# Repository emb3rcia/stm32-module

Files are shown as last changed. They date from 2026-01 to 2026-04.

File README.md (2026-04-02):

# stm32-module
Hello! This is my first MCU devboard, made for HackClub's Blueprint program. It features 66 goldpins, USB-C (USB-FS standard) port for data AND power, integrated 3.3V and 1.8V LDO and ESD protection on VBUS, DATA channels and CC channels! It uses 4 layer pcb (Front and Back are for power, IN1 and IN2 for GPIO connection). It uses STM32H7 64-LQFP Package MCU on it! I made it so I can have some devboard on hand as one-for-all. This is why theres so much power in this thing (384MHz!!!) and this many GPIO ports, and also why this has 1.8V LDO. You use it like any other devboard, **but note that it probably wont fit on breadboard, as it doesnt have the required distance present between connectors**

## Why i made it?

I thought it will be good learning project as well as giving me access to prototyping with mcu before commiting to making pcb. And i was right!

## What i learned:

Mainly how to deal with tight connection layout on PCB near MCU

# Images
Schematic v1 (old)

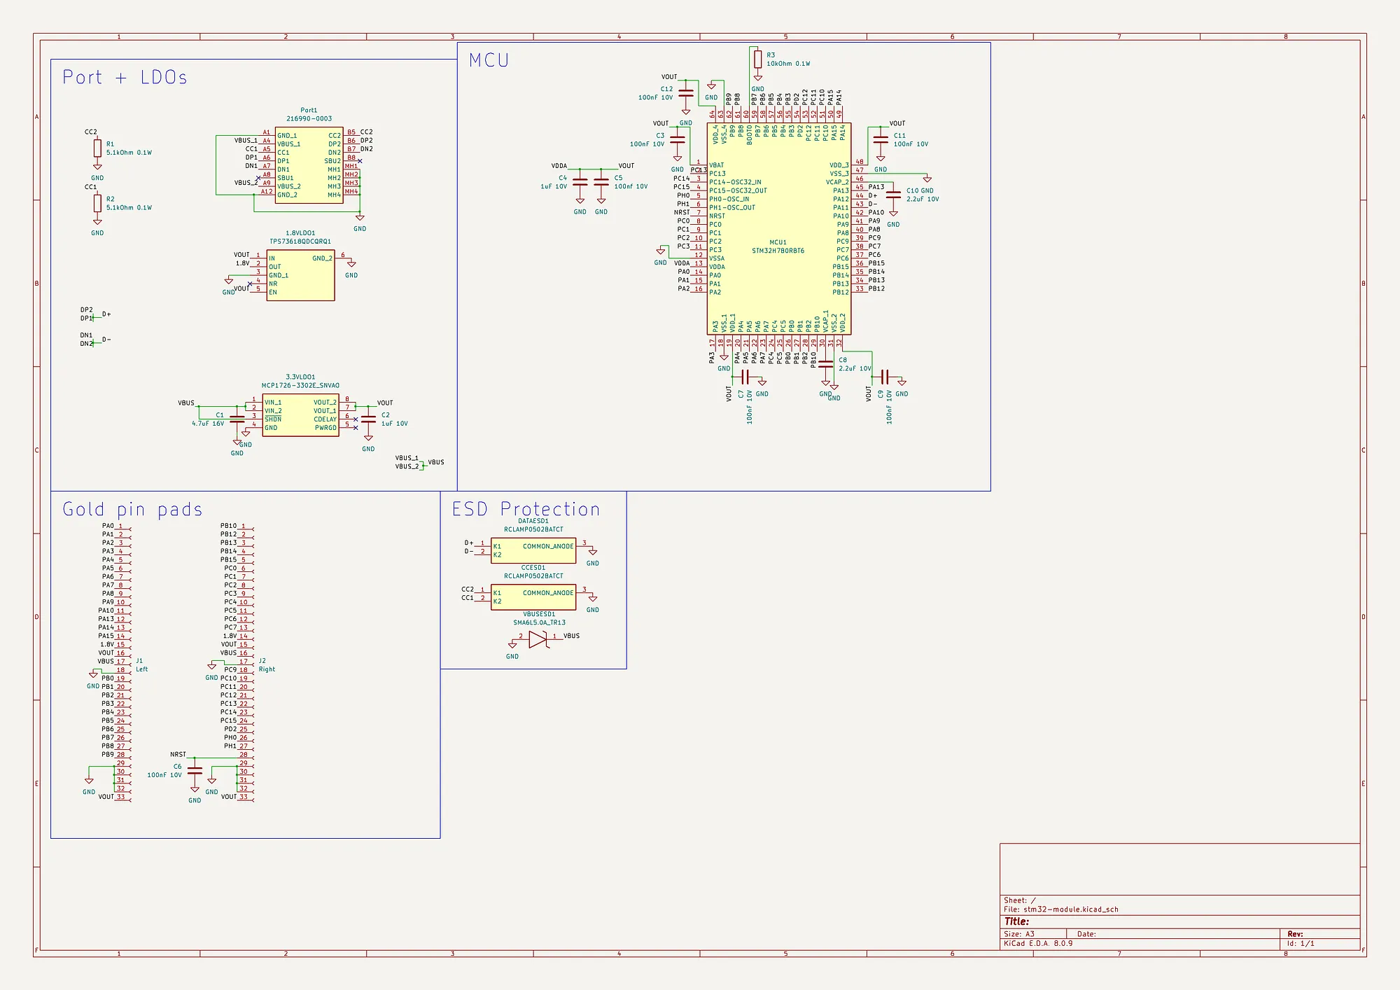
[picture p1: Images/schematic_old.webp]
Schematic v1 (old)


Schematic v1.5 (new, work in progress)

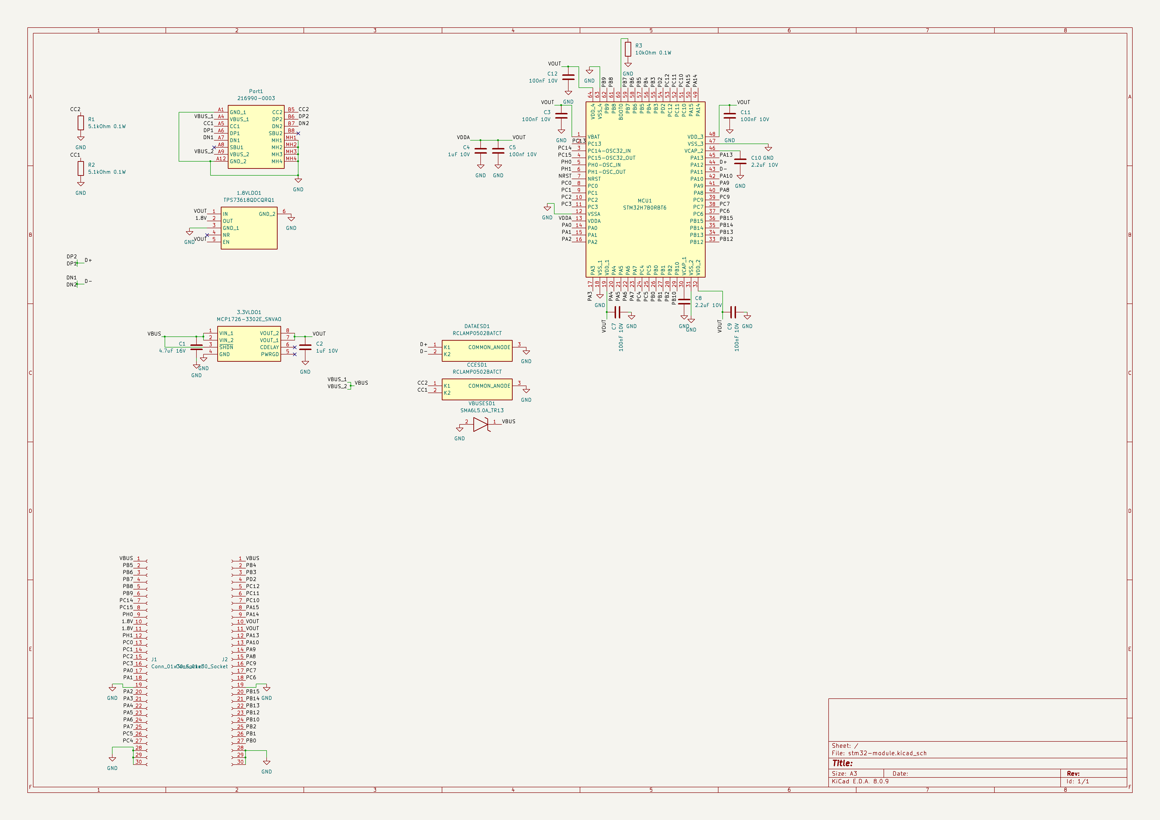
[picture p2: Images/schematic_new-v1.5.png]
Schematic v1.5 (new, work in progress)


Schematic v2 (new)

Schematic v2 (new)

PCB v1 (old, view via kicanvas so low quality screenshot, sorry)

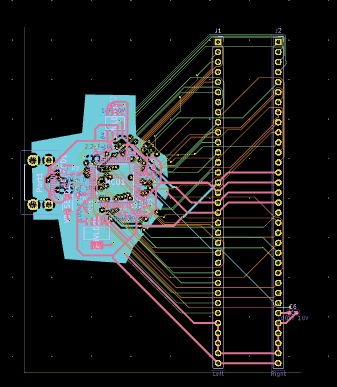
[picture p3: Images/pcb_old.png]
PCB v1 (old, view via kicanvas so low quality screenshot, sorry)


PCB v2 (new)

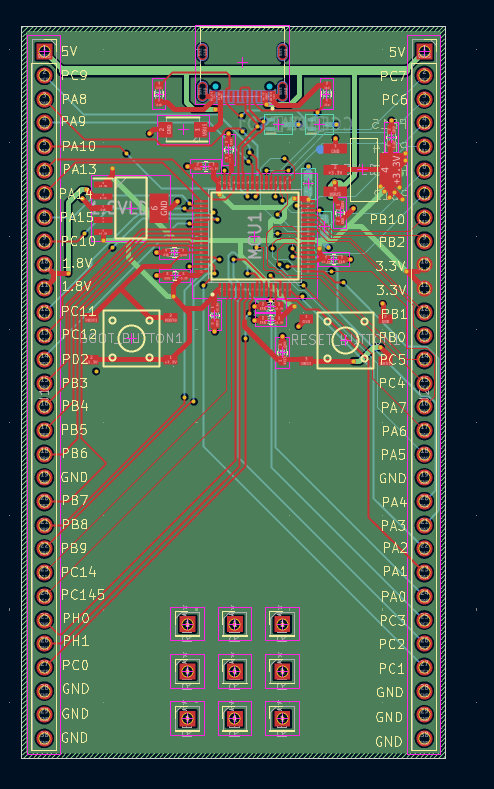
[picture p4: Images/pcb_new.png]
PCB v2 (new)


3D (new)

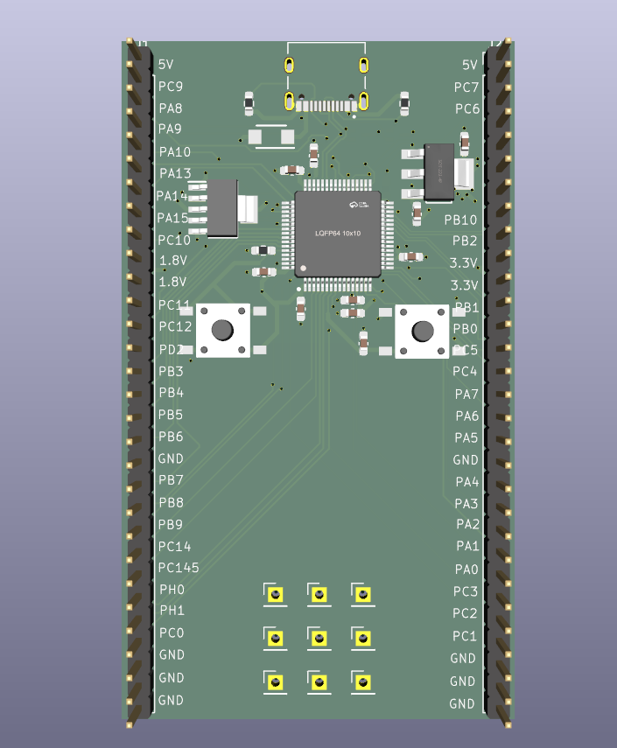
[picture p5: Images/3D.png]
3D (new)


# Q&A (no one said that but I want to include that lol)
> Traces look ugly

It is my second completed project overall. Also they weren't like high speed eg pcie so I just connected them as well as I can! I will try to make them nicer before production, but no promises. EDIT: Tried to make them nicer when rerouting everything, it worked like you can see.

# BOM
|Item |Description |Needed|Ordered|Why more/less? |Unit Price ($)|Total Price ($) |URL |
|---|---|---|---|---|---|---|---|
|ST STM32H7B0RBT6 |MCU |1 |1 |- |10.08$ |10.08$ |https://www.lcsc.com/product-detail/C730226.html |
|SEMTECH RCLAMP0502BATCT |CC and DATA lines esd |2 |5 |5 is minimal order amount |0.24$ |1.21$ |https://www.lcsc.com/product-detail/C117553.html |
|Littelfuse SMA6L5.0A |VBUS line esd |1 |1 |- |0.79$ |0.79$ |https://www.lcsc.com/product-detail/C1974860.html|
|BL BL8072CLTR33 |3.3V LDO |1 |5 |5 is minimal order amount |0.19$ |0.97$ |https://www.lcsc.com/product-detail/C843780.html |
|TI TPS73618QDCQRQ1 |1.8V LDO |1 |1 |- |1.54$ |1.54$ |https://www.lcsc.com/product-detail/C2877946.html|
|muRata GRM188Z71C475KE21D |4.7uF capacitor |1 |10 |10 is minimal order amount |0.07$ |0.68$ |https://www.lcsc.com/product-detail/C389010.html |
|Samsung Electro-Mechanics CL10A105KA8NNNC|1uF capacitor |2 |0 |I have 48 left from other project|- |- |https://www.lcsc.com/product-detail/C5673.html |
|VISHAY VJ0603Y104JXQCW1BC |100nF decap capacitor |7 |10 |sold in increments of 5 |0.08$ |0.81$ |https://www.lcsc.com/product-detail/C3834925.html|
|Samsung Electro-Mechanics CL10A225KO8NNNC|2.2uF capacitor |2 |50 |50 is minimal order amount |0.0062$ |0.31$ |https://www.lcsc.com/product-detail/C23630.html  |
|UNI-ROYAL 0603WAF5101T5E |5.1kOhm 0.1w CC resistor |2 |100 |100 is minimal order amount |0.0012$ |0.12$ |https://www.lcsc.com/product-detail/C23186.html  |
|VISHAY CRCW060310K0DHEAP |10kOhm pull-up/down resistor|2 |5 |5 is minimal order amount |0.12$ |0.58$ |https://www.lcsc.com/product-detail/C3917708.html|
|SHOU HAN TS6643TP 250gf 009 |BOOT and NRST button |2 |50 |50 is minimal order amount |0.0167$ |0.84$ |https://www.lcsc.com/product-detail/C5342967.html|
|SHOU HAN TYPE-C 16PIN 2MD(073) |USB-C plug |1 |20 |20 is minimal order amount |0.06$ |1.26$ |https://www.lcsc.com/product-detail/C2765186.html|
|PCB |PCB |1 |5 |5 is minimal order amount |- |7$+1.5$ delivery|https://jlcpcb.com/ |

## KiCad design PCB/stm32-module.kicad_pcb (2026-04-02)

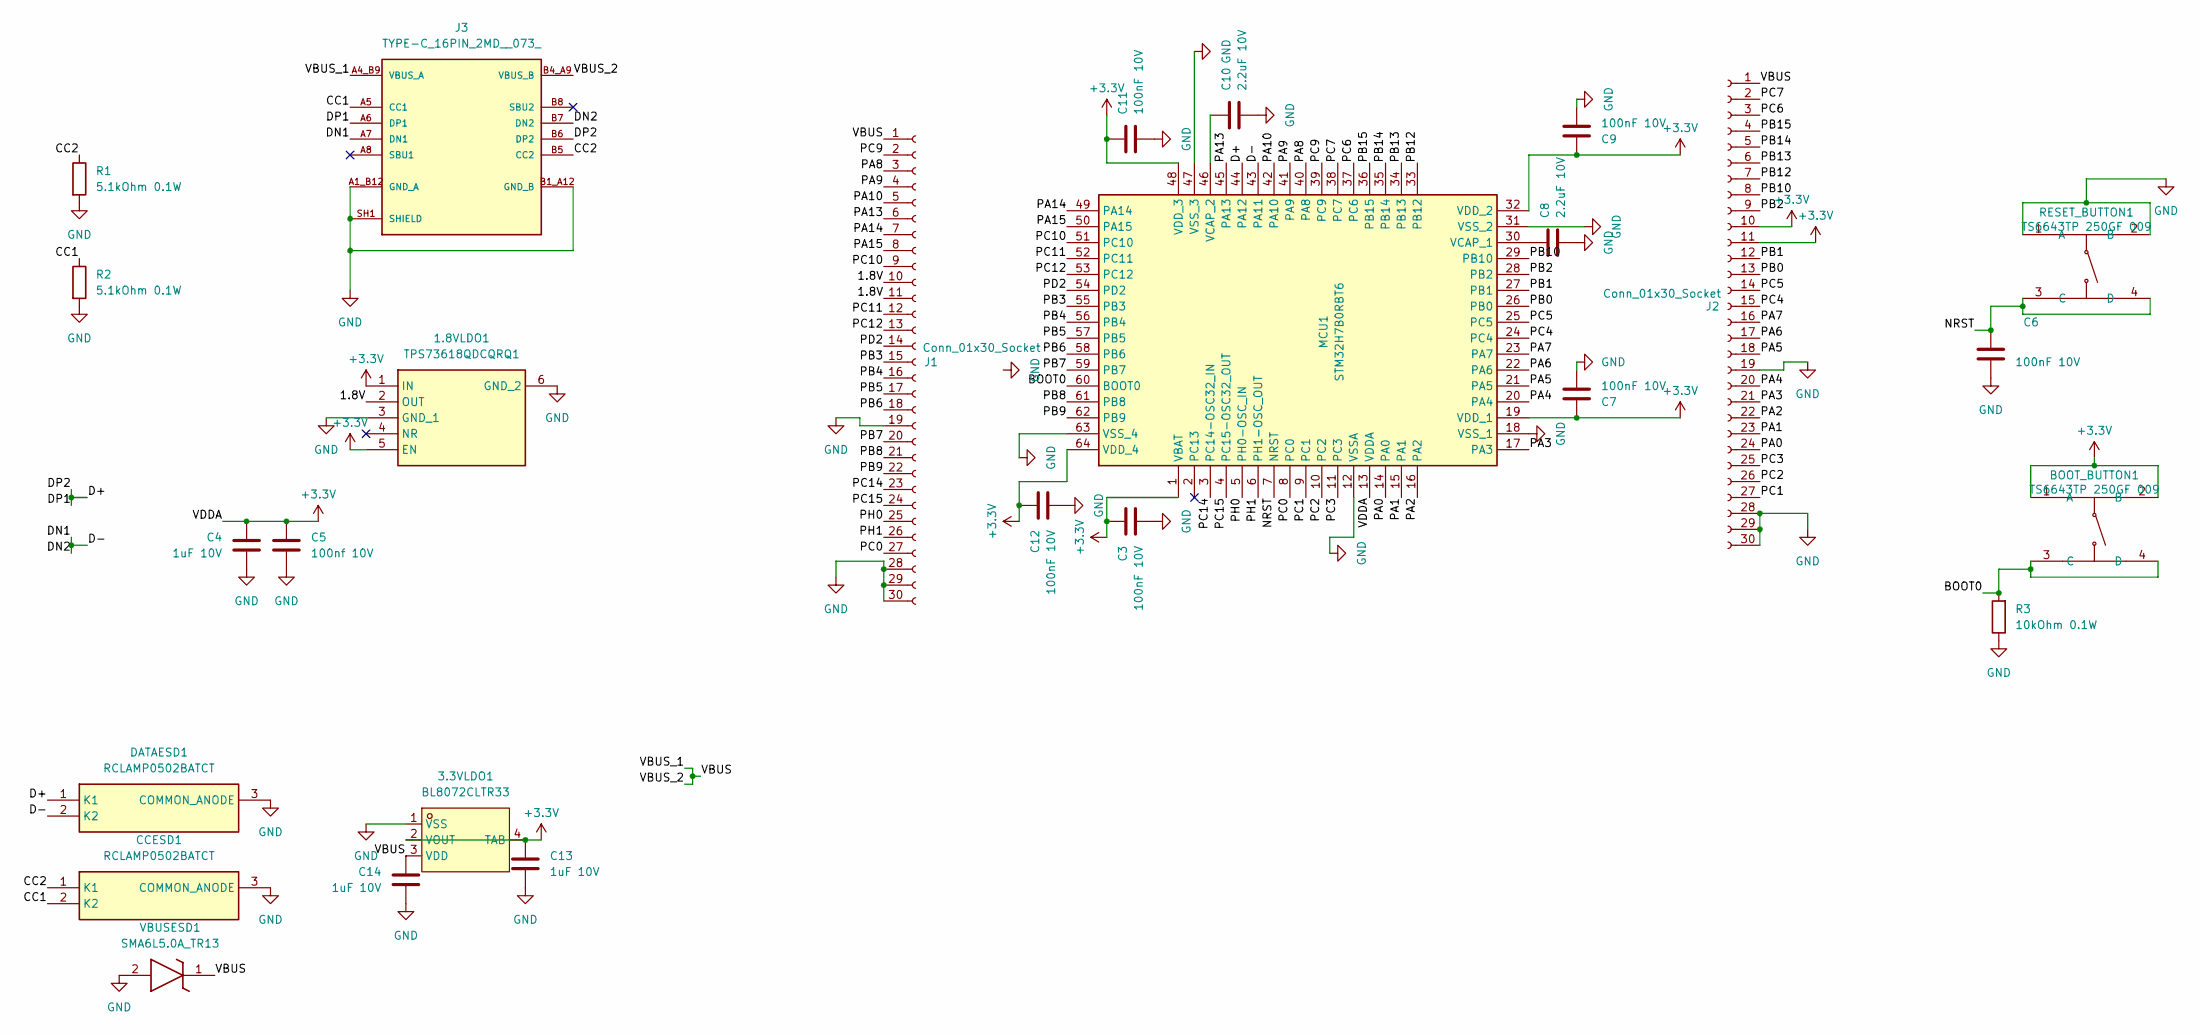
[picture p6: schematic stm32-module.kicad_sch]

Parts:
1.8VLDO1: TPS73618QDCQRQ1; SOT127P706X180-6N; Manufacturer_Part_Number TPS73618QDCQRQ1; Mouser Part Number 595-TPS73618QDCQRQ1
3.3VLDO1: BL8072CLTR33; SOT-223-3_L6.5-W3.4-P2.30-LS7.0-BR; LCSC Part C843780
BOOT_BUTTON1: TS6643TP 250GF 009; SW-SMD_4P-L6.2-W6.0-P4.50-LS9.0; LCSC Part C5342967
C3, C6, C7, C9, C11, C12: 100nF 10V; C_0603_1608Metric_Pad1.08x0.95mm_HandSolder
C4, C13, C14: 1uF 10V; C_0603_1608Metric_Pad1.08x0.95mm_HandSolder
C5: 100nf 10V; C_0603_1608Metric_Pad1.08x0.95mm_HandSolder
C8, C10: 2.2uF 10V; C_0603_1608Metric_Pad1.08x0.95mm_HandSolder
CCESD1: RCLAMP0502BATCT; SOT50P160X90-3N; Manufacturer_Part_Number RCLAMP0502BATCT; Mouser Part Number 947-RCLAMP0502BATCT
DATAESD1: RCLAMP0502BATCT; SOT50P160X90-3N; Manufacturer_Part_Number RCLAMP0502BATCT; Mouser Part Number 947-RCLAMP0502BATCT
J1, J2: Conn_01x30_Socket; PinSocket_1x30_P2.54mm_Vertical
J3: TYPE-C_16PIN_2MD__073_; SHOUHAN_TYPE-C_16PIN_2MD__073_; PARTREV A
MCU1: STM32H7B0RBT6; QFP50P1200X1200X160-64N; Manufacturer_Part_Number STM32H7B0RBT6; Mouser Part Number 511-STM32H7B0RBT6
R1, R2: 5.1kOhm 0.1W; R_0603_1608Metric_Pad0.98x0.95mm_HandSolder
R3: 10kOhm 0.1W; R_0603_1608Metric_Pad0.98x0.95mm_HandSolder
RESET_BUTTON1: TS6643TP 250GF 009; SW-SMD_4P-L6.2-W6.0-P4.50-LS9.0; LCSC Part C5342967
VBUSESD1: SMA6L5.0A_TR13; SODFL4626X140N; Manufacturer_Part_Number SMA6L5.0A/TR13

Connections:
+3.3V: 1.8VLDO1.1 (IN), 1.8VLDO1.5 (EN), 3.3VLDO1.2 (VOUT), 3.3VLDO1.4 (TAB), BOOT_BUTTON1.1 (A), BOOT_BUTTON1.2 (B), C3.1, C4.1, C5.1, C7.1, C9.1, C11.1, C12.1, C13.1, J2.10, J2.11, MCU1.1 (VBAT), MCU1.13 (VDDA), MCU1.19 (VDD_1), MCU1.32 (VDD_2), MCU1.48 (VDD_3), MCU1.64 (VDD_4)
/1.8V: 1.8VLDO1.2 (OUT), J1.10, J1.11
/BOOT0: BOOT_BUTTON1.3 (C), BOOT_BUTTON1.4 (D), MCU1.60 (BOOT0), R3.2
/CC1: CCESD1.2 (K2), J3.A5 (CC1), R2.1
/CC2: CCESD1.1 (K1), J3.B5 (CC2), R1.1
/D+: DATAESD1.1 (K1), J3.A6 (DP1), J3.B6 (DP2), MCU1.44 (PA12)
/D-: DATAESD1.2 (K2), J3.A7 (DN1), J3.B7 (DN2), MCU1.43 (PA11)
/NRST: C6.1, MCU1.7 (NRST), RESET_BUTTON1.3 (C), RESET_BUTTON1.4 (D)
/PA0: J2.24, MCU1.14 (PA0)
/PA1: J2.23, MCU1.15 (PA1)
/PA2: J2.22, MCU1.16 (PA2)
/PA3: J2.21, MCU1.17 (PA3)
/PA4: J2.20, MCU1.20 (PA4)
/PA5: J2.18, MCU1.21 (PA5)
/PA6: J2.17, MCU1.22 (PA6)
/PA7: J2.16, MCU1.23 (PA7)
/PA8: J1.3, MCU1.40 (PA8)
/PA9: J1.4, MCU1.41 (PA9)
/PA10: J1.5, MCU1.42 (PA10)
/PA13: J1.6, MCU1.45 (PA13)
/PA14: J1.7, MCU1.49 (PA14)
/PA15: J1.8, MCU1.50 (PA15)
/PB0: J2.13, MCU1.26 (PB0)
/PB1: J2.12, MCU1.27 (PB1)
/PB2: J2.9, MCU1.28 (PB2)
/PB3: J1.15, MCU1.55 (PB3)
/PB4: J1.16, MCU1.56 (PB4)
/PB5: J1.17, MCU1.57 (PB5)
/PB6: J1.18, MCU1.58 (PB6)
/PB7: J1.20, MCU1.59 (PB7)
/PB8: J1.21, MCU1.61 (PB8)
/PB9: J1.22, MCU1.62 (PB9)
/PB10: J2.8, MCU1.29 (PB10)
/PB12: J2.7, MCU1.33 (PB12)
/PB13: J2.6, MCU1.34 (PB13)
/PB14: J2.5, MCU1.35 (PB14)
/PB15: J2.4, MCU1.36 (PB15)
/PC0: J1.27, MCU1.8 (PC0)
/PC1: J2.27, MCU1.9 (PC1)
/PC2: J2.26, MCU1.10 (PC2)
/PC3: J2.25, MCU1.11 (PC3)
/PC4: J2.15, MCU1.24 (PC4)
/PC5: J2.14, MCU1.25 (PC5)
/PC6: J2.3, MCU1.37 (PC6)
/PC7: J2.2, MCU1.38 (PC7)
/PC9: J1.2, MCU1.39 (PC9)
/PC10: J1.9, MCU1.51 (PC10)
/PC11: J1.12, MCU1.52 (PC11)
/PC12: J1.13, MCU1.53 (PC12)
/PC14: J1.23, MCU1.3 (PC14-OSC32_IN)
/PC15: J1.24, MCU1.4 (PC15-OSC32_OUT)
/PD2: J1.14, MCU1.54 (PD2)
/PH0: J1.25, MCU1.5 (PH0-OSC_IN)
/PH1: J1.26, MCU1.6 (PH1-OSC_OUT)
/VBUS: 3.3VLDO1.3 (VDD), C14.1, J1.1, J2.1, J3.A4_B9 (VBUS_A), J3.B4_A9 (VBUS_B), VBUSESD1.1 (K)
GND: 1.8VLDO1.3 (GND_1), 1.8VLDO1.6 (GND_2), 3.3VLDO1.1 (VSS), C3.2, C4.2, C5.2, C6.2, C7.2, C8.2, C9.2, C10.2, C11.2, C12.2, C13.2, C14.2, CCESD1.3 (COMMON_ANODE), DATAESD1.3 (COMMON_ANODE), J1.19, J1.28, J1.29, J1.30, J2.19, J2.28, J2.29, J2.30, J3.A1_B12 (GND_A), J3.B1_A12 (GND_B), J3.SH1 (SHIELD), J3.SH2 (SHIELD), J3.SH3 (SHIELD), J3.SH4 (SHIELD), MCU1.12 (VSSA), MCU1.18 (VSS_1), MCU1.31 (VSS_2), MCU1.47 (VSS_3), MCU1.63 (VSS_4), R1.2, R2.2, R3.1, RESET_BUTTON1.1 (A), RESET_BUTTON1.2 (B), VBUSESD1.2 (A)
unnamed: C8.1, MCU1.30 (VCAP_1)
unnamed: C10.1, MCU1.46 (VCAP_2)

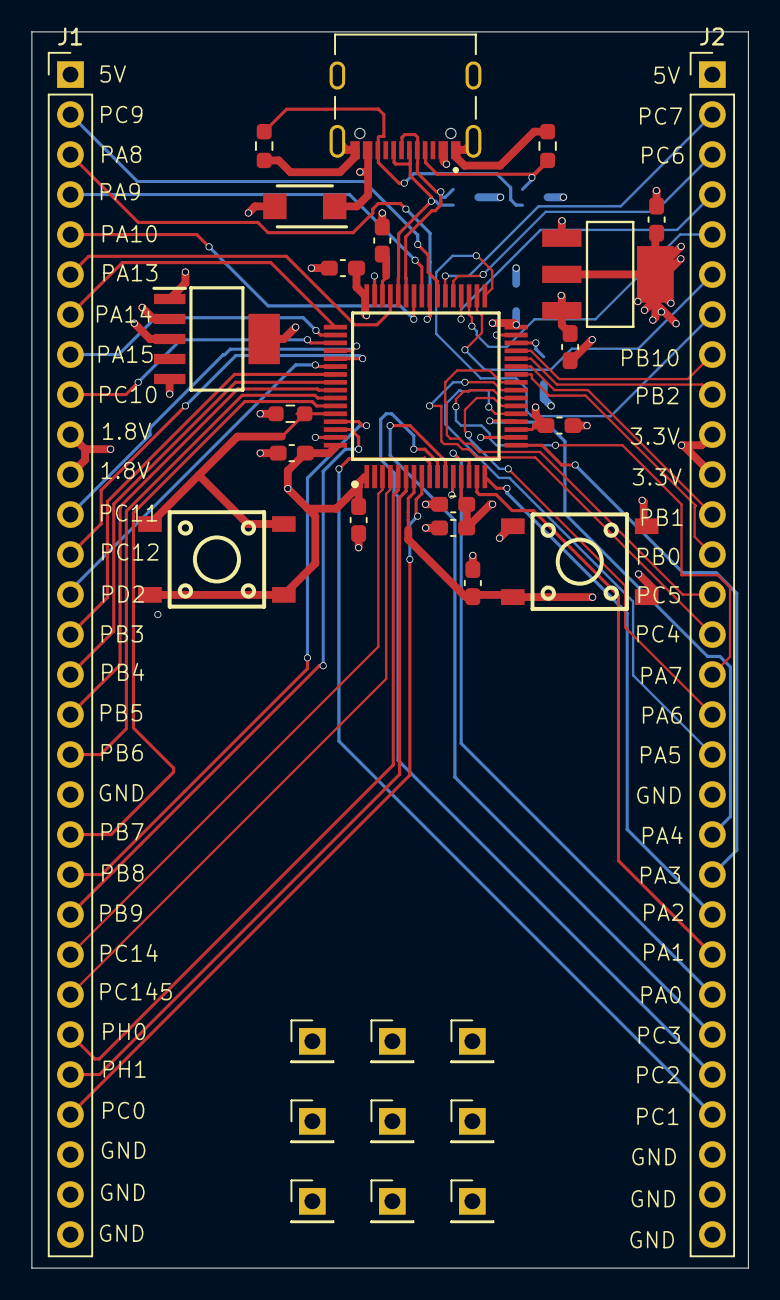
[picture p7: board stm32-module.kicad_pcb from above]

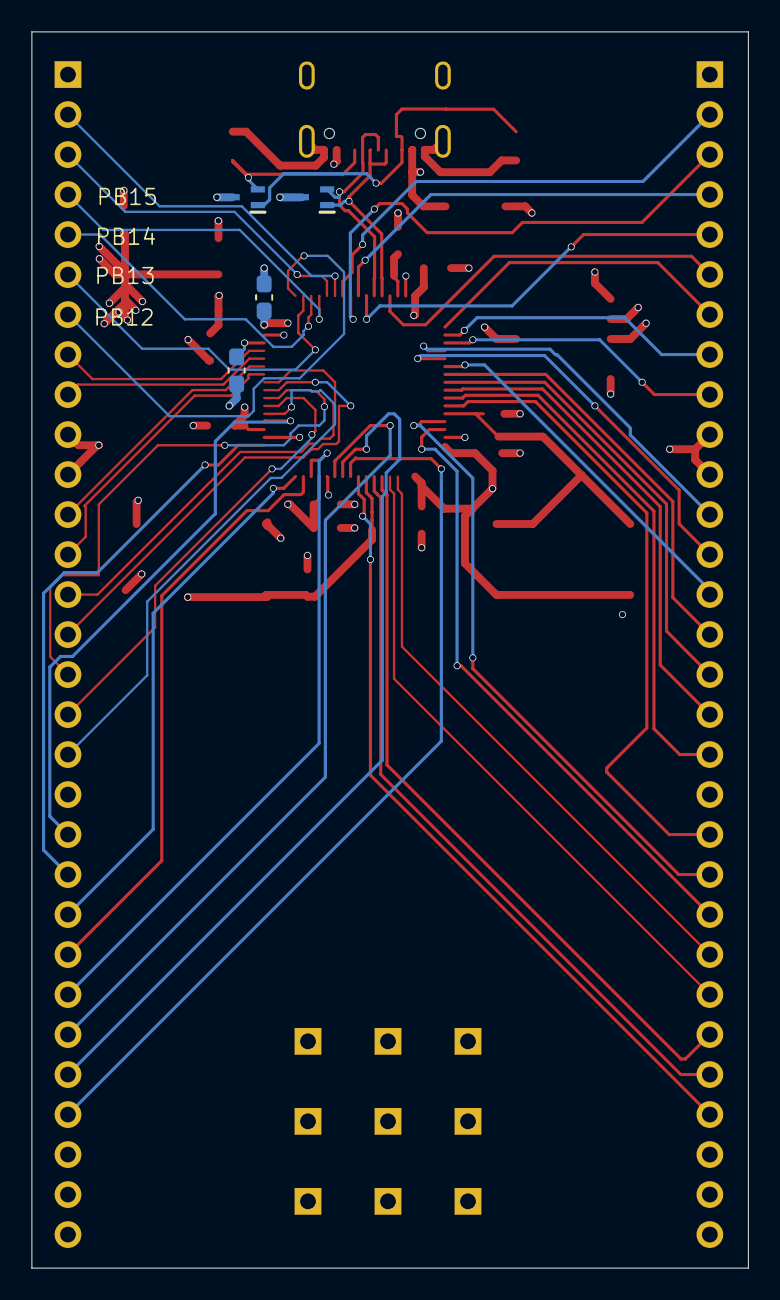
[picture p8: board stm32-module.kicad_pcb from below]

Board: 4 copper layers, 45.5 x 78.5 mm, 26 parts (4 on the bottom side), 58 nets.

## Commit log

2026-01-30 Added images to rom, also rerouted everything
    [STM32H7B0RBT6-pinout.csv, stm32-module.kicad_pcb, stm32-module.kicad_sch]
2026-01-31 Changed readme to reflect different switch chosen due to availability
2026-01-31 Changed readme, pcb and schematic to reflect different connector chosen due to availability
    [stm32-module.kicad_pcb, stm32-module.kicad_sch]
2026-01-31 Added bom to bom.csv and readme.md
    [bom.csv]
2026-02-01 Added connector footprint with 3d model
    [stm32-module.kicad_pcb, stm32-module.kicad_sch]
2026-02-01 Added hat pins
    [stm32-module.kicad_pcb]
2026-02-04 Corrected button wiring
    [STM32H7B0RBT6-pinout.csv, bom.csv, stm32-module.kicad_pcb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]
2026-02-19 Changed README.md
    [bom.csv]
2026-02-21 Updated bom
    [bom.csv]
2026-03-16 delay tuned usb pair
    [stm32-module.kicad_pcb]
2026-03-16 Delay tuned USB traces
    [stm32-module.kicad_pcb]
2026-03-17 updated gerbers
2026-03-18 updated bom to reflect vbus change
2026-03-18 updated bom to reflect resistor change
2026-04-02 Changed ldo due to availability
    [STM32H7B0RBT6-pinout.csv, bom.csv, stm32-module.kicad_pcb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]
2026-04-02 changed images to reflect changes
    [stm32-module.kicad_pcb]
